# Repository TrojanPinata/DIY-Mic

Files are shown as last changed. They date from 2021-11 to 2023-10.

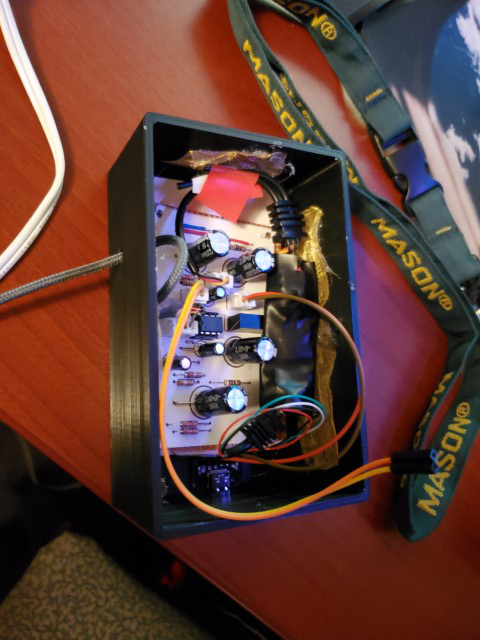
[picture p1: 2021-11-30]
pics/Assembled-Box (Small).jpg

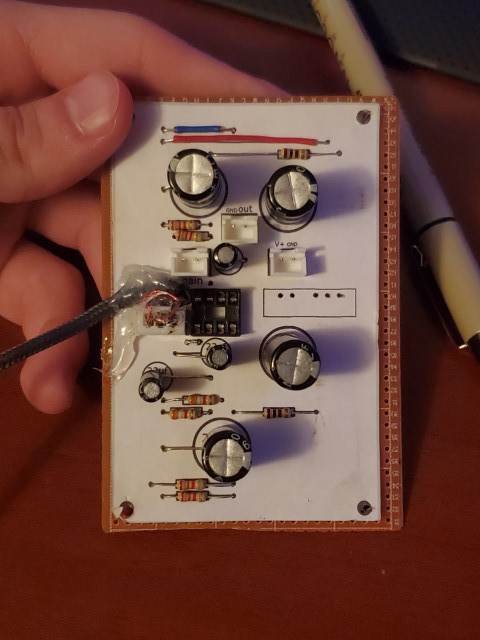
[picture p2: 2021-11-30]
pics/Partially-Assembled (Small).jpg

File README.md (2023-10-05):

# DIY-Mic
A DIY microphone built using the design of DIY Perks and modified by me. I wanted a decent mic and I didn’t want to spend the money on one, so when I saw this video it seemed like the perfect opportunity for me to both have fun with a electronics project and get a decent mic.

# Credit
This would not be possible without DIY Perks and the resources he provided. The stripboard and base wiring diagram are extremely helpful as well as his overall attention to detail. Video link here: https://www.youtube.com/watch?app=desktop&v=LoQu3XXIayc

# Acquiring Parts
For this build, there are a number of parts you will need. In the video he goes all out in brass, which for most of us at home, seems absurd because of how uncommon it is to have the exact diameter of brass tubing or brass mesh lying around. I ran into this problem early on, so I designed a box and lid for mine that should work in place of a ton of brass and wood and is easily 3d printable (STLs above). I know most people don't have 3d printers, but I feel like this is slightly more accessible for those without hordes of tools. I also used a mic arm I found in the trash to make the arm instead of building it. So, with the 'housing' out of the way, everything else can be found in this list (or at least what I used/needed):

https://docs.google.com/spreadsheets/d/1pQlkRerO5geoDNLEWXTUVbyJalM7nESn/edit#gid=497893649

As you can probably tell, the pricing is pretty high compared to the sticker price. That was the number I was able to get it down to after some alternatives (and using the wrong materials and finding out they don’t work. The electronics can either be found on alibaba or ebay, I chose ebay because that was the only way I could finish this in less then 2 months. With all of that, I nicked a old audio cable, a old rc car motor, and some resistors in order to start building.

# Actually Building the Thing
The first thing I did (and this pretty much goes with the order the parts arrived to me) was the preamp box. I put some brass mesh on the bottom and glued the template on some protoboard, soldered all of the parts on and drilled corner holes. In hindsight, the pegs I included were pretty useless (and off center) so they should probably just be removed. I layered some tape over the bottom mesh to prevent shorts and plopped the whole thin in. I then added the potentiometer to the lid. Note, I live in the US, so I was unable to get a THAT1512, and I had to go with an INA217. This isn't really a problem, just know that on my final build, I attached a 2.2kOhm resistor to the potentiometer because of how the gain settings work. I assume there may be some overall gain differences, but we'll get to that in the review section. I pretty much did that and threw in the ADC (Analog Digital Converter) with some tape covering it. I ordered a pretty cheap one, but it has a led and I kind of like that because of how much easier it made troubleshooting. All of these parts can be connected to the main board and the ADC can be connected to the USB-C breakout board. Power wires can be connected and that should be everything that is directly connected.

Partially Assembled:



Some notes real quick before putting anything on the board:



The two capacitors on the right need to be flipped 180 degrees so the polarities are swapped, and all of the rest are fine, with the white being positive and dark being negative. Other than that, you can build it however you want. I found that its better to use a little bit thicker audio cable, because the stuff that i used was really thin and I ended up having to solder it a bit to get the connectors to stay on.



And on that note lets talk about the cables. So yes, you can use solder removing copper strips like he did. But I had extremely bad luck with mine all just being flat to begin with, and thus not folding back into a tube. So as a result, I just ordered some proper sheathing. Honestly, worth it. I ended up threading the enameled wires through much easier than I thought it would be. So, with those two out of the way, IU soldered them together and used a heatshrink for the binding. Now, I just want to note that the way DIY Perks sands the enamel off of those thin wires is correct, however, be extremely careful because if you go too far, they are super easy to short (trust me I know from experience). So, with that, you can plug the cable into the preamp and work on the mic. 



The mic, from my experience, has the parts that take the longest to get here. First of all, if you can get a JLI mic module, be my guest, but they seem to be always out of stock. I ordered mine from another place for a significant markup and I'm not even mad. At least it’s here. The transistors took a hot minute to get here (they were the last thing I needed, and I actually moved on to another project I got so sick of waiting on them. Once they did arrive though, its pretty much exactly as he said. However, I should note my module housing is also 3d printed and the grills are shaped using 3d printed parts. Crushed the mesh in between the mold and formed the grills, soldered them with the transistor mic combo like a sandwich, and jammed it into the housing. I added all of those holes for maximum sound quality, and it seems to work. I will note that you should probably put something between the grill and transistor, as well as between the legs due to possible shorting, as that is what caused a lot of my early trouble. With that, that’s basically everything. I used some tape to secure the lid onto the box and hot glue to keep some loose things secured and it just kind of works. 



The rear of the module is really jank for me. Don't do this lol:



# Review
Overall its a good mic. I've been using it for the past few weeks and everyone who’s seen it really likes it. It's kind of scuffed but sounds fantastic (most of the time). I should note that I had a insane amount of gain until I added a resistor between the potentiometer. I still do, and I probably just need more shielding, but it sounds fine over discord and for personal use so I don't mind too much. I'll fix it when I need it. 

The big things about this project I would note for anyone looking to do this is that a.) it costs more then you expect, b.) it's not going to look anything like the video, and c.) there will be more noise then you think there will be. Other then that, happy building!

# Edit - 02/11/2022
Hello, I thought I was done with this project but let me tell you I've got a update that may interest you. Back when I was picking out the parts for this, I chose to use a INA217 because it was available and the only way for me to get a THAT1512 was a long 4 month wait from the UK. So, I bought the THAT1512 and the INA217 and hoped it would work out. I used the INA217 for the past few months and I can say its definitely good. Not great, not bad, just good. And I was happy with that. I had to use a higher resistance resistor in place of the potentiometer but overall, I didn't really mind it. There was a little bit of background noise at some frequencies, but I just thought that was my bad shielding.

I just got my THAT1512, slapped that bad boy in there and let me tell you, it's a whole world of difference. The two chips should be very electrically similar according to their data sheets, with only a little bit of gain differences, but the difference is insane. No more noise went back to the potentiometer, better volume (even at the same levels), and overall, a better time. Anyway, hope that interests you. They're kind of hard to find so if you can get one then do. Otherwise INA217 is still pretty good.

# Update - 10/05/2023
Hello! It has been a while. I never thought I'd update this repository again, but I just wanted to stop in after a while and clean up by bringing some modifications to the original project and overall design. I found the original mic design to be pretty cool, but horribly inconvenient to use. I ended up switching to another microphone for a while, but I thought I'd come back with some real quality of life changes to make this actually usable for me. The main things I changed were swapping the housing for a BM-800 microphone body (one of the worst sounding mics on the market - but cheap to fit with the theme) and designing a PCB which follows the original stripboard. My PCBs totaled a cool five dollars, and the quality of the entire thing is significantly higher. 

The end result was much better than the original, with significantly less noise and much more versatility. I added the KiCad files to the repo but don’t expect too much. I found the mic gets a bit hotter and has a much lower gain setting (100 ohms) due to the lower noise but is overall pretty good – especially when compared to the original. These upgrades make this 99% more usable for me and hopefully if you either still use this project or something similar this update is helpful.

mic exposed

mic together

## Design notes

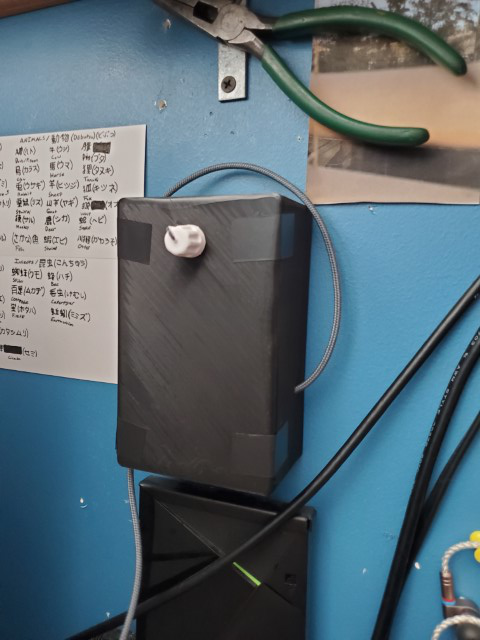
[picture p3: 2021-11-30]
pics/Magic-Box (Small).jpg

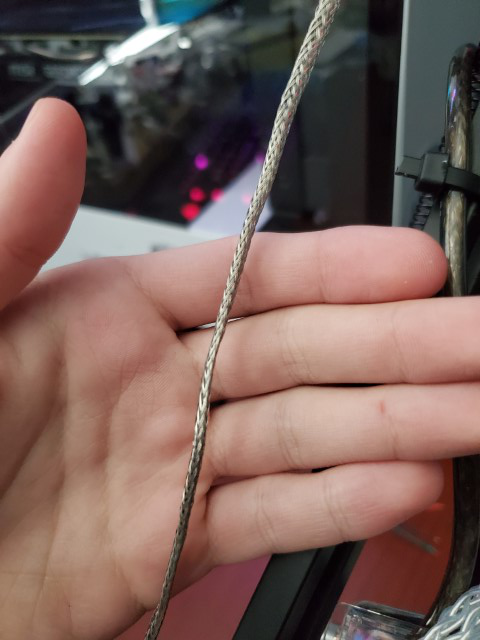
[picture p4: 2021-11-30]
pics/Cable (Small).jpg

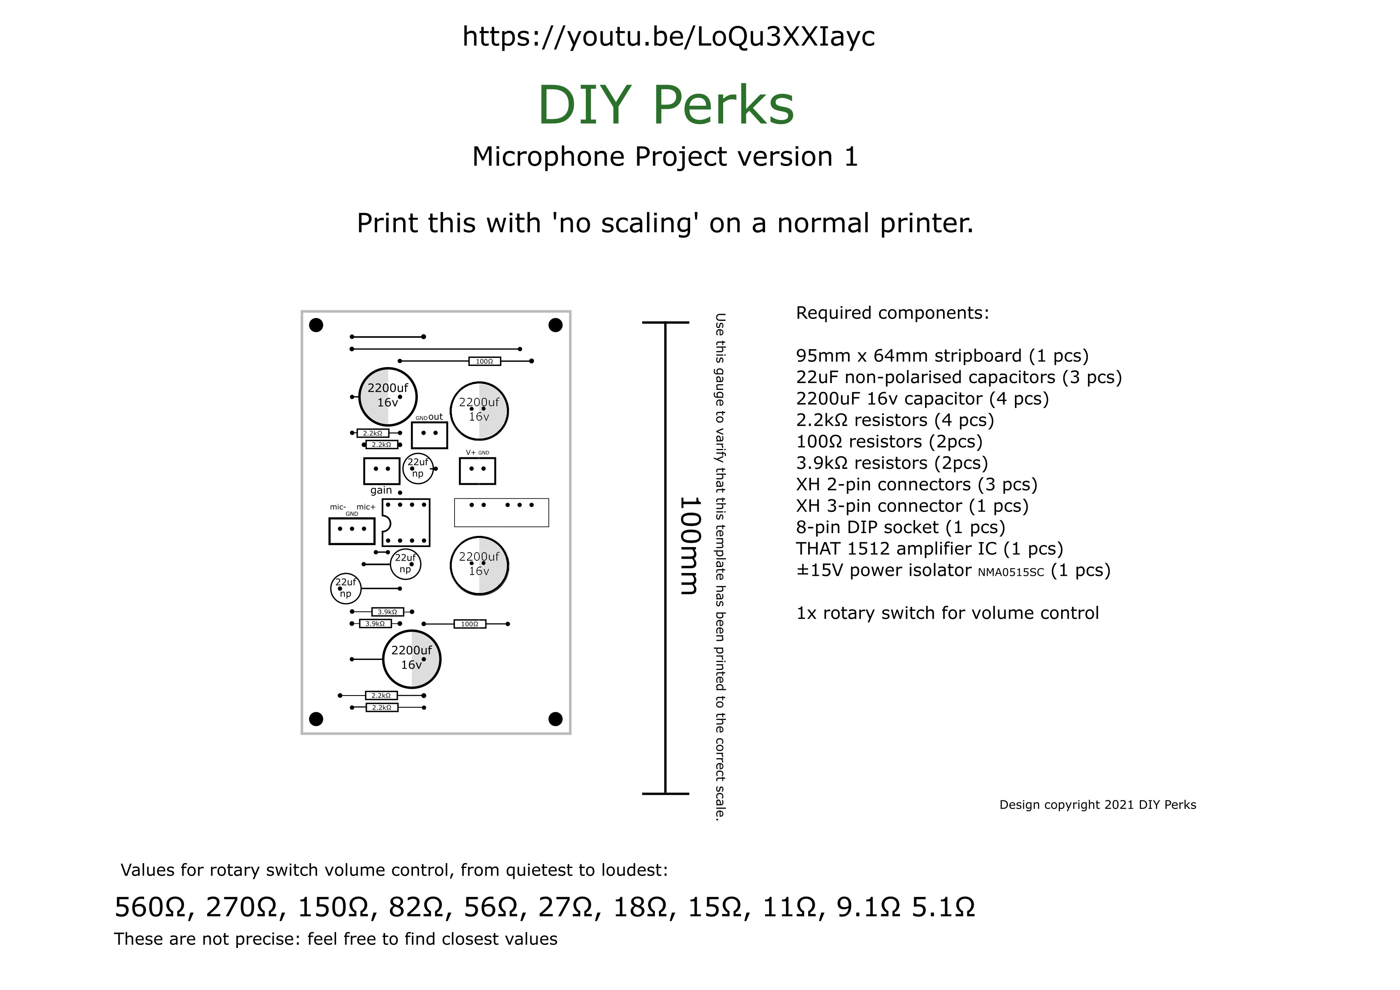
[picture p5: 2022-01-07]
new stripboard.png

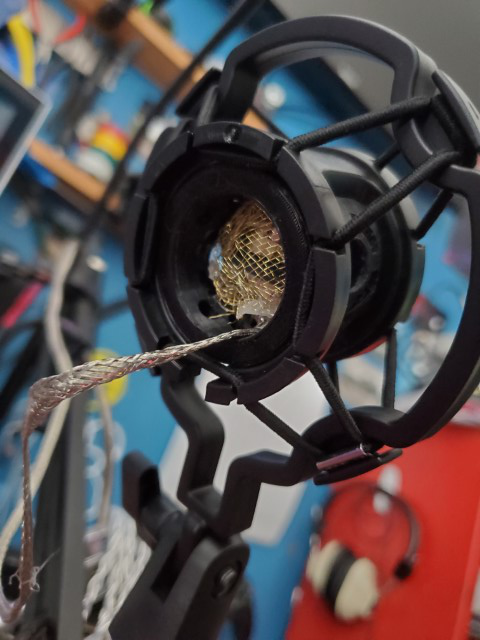
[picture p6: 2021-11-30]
pics/Rear (Small).jpg

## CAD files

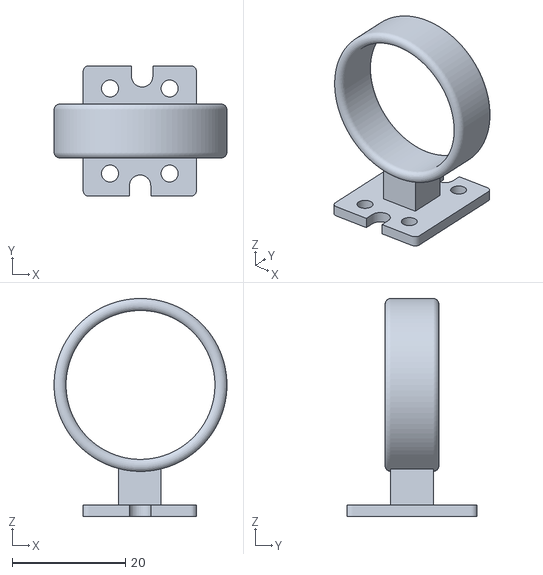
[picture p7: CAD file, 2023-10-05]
stls/micmoduleholder.stl
30.5 x 23.0 x 38.4

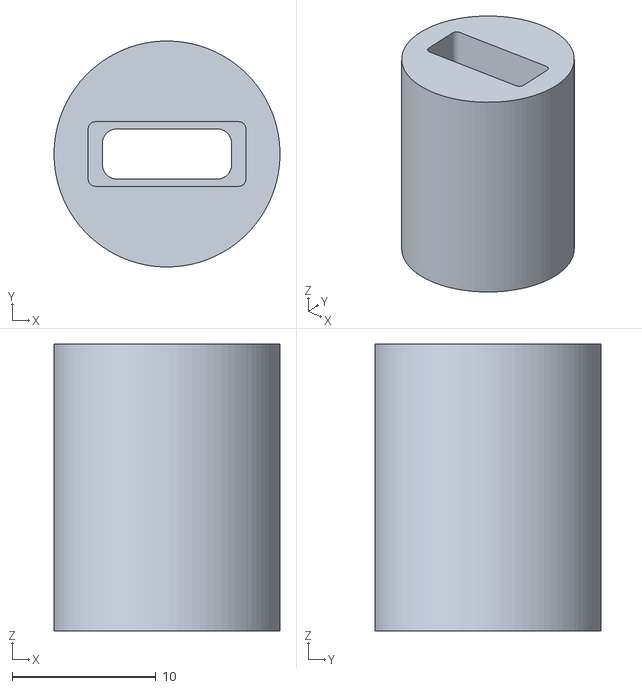
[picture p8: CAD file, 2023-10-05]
stls/xlr2usbc.stl
15.7 x 15.7 x 20.0

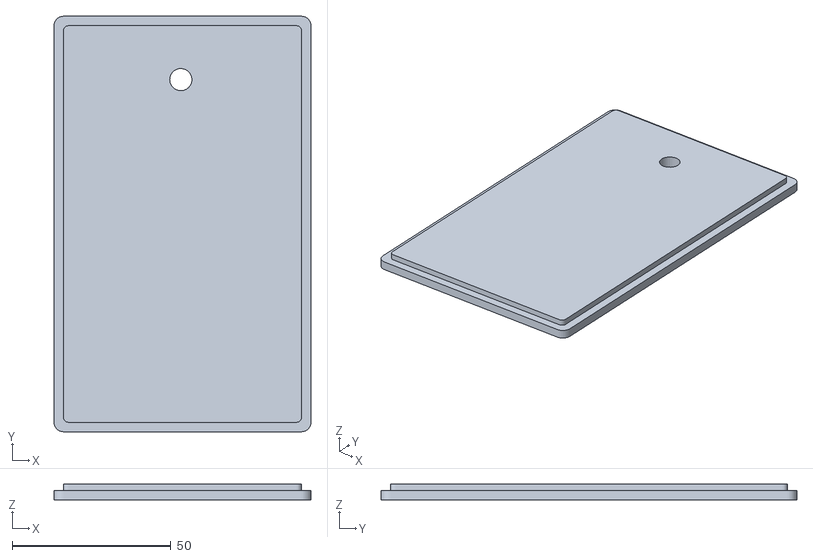
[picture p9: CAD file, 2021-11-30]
stls/top v3.stl
81.0 x 131.0 x 5.00

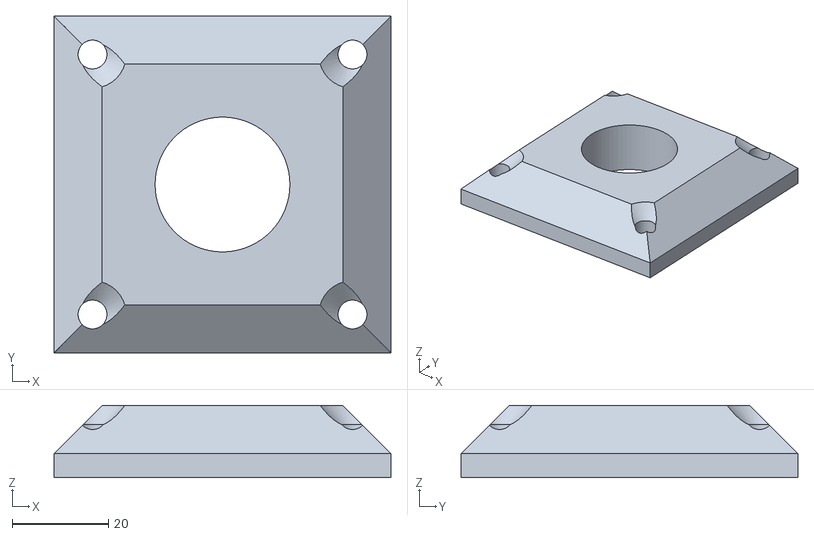
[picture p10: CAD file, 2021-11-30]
stls/press base v1.stl
70.0 x 70.0 x 15.0

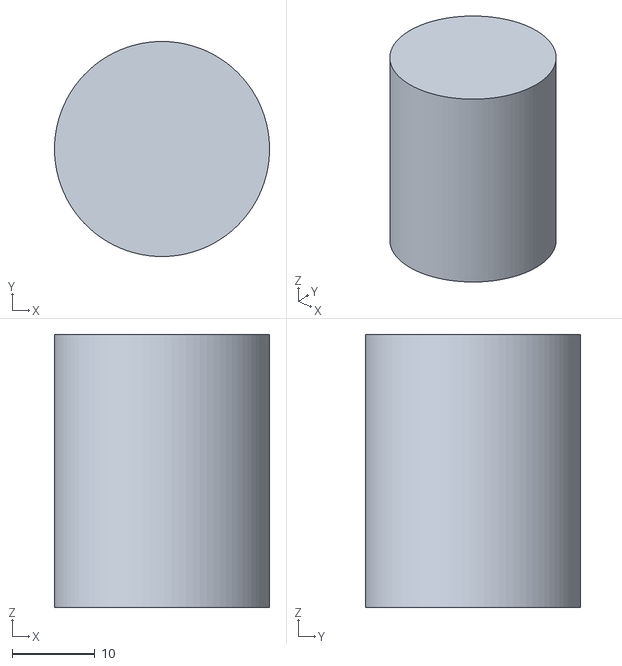
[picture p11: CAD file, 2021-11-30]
stls/press rod v2.stl
26.0 x 26.0 x 33.0

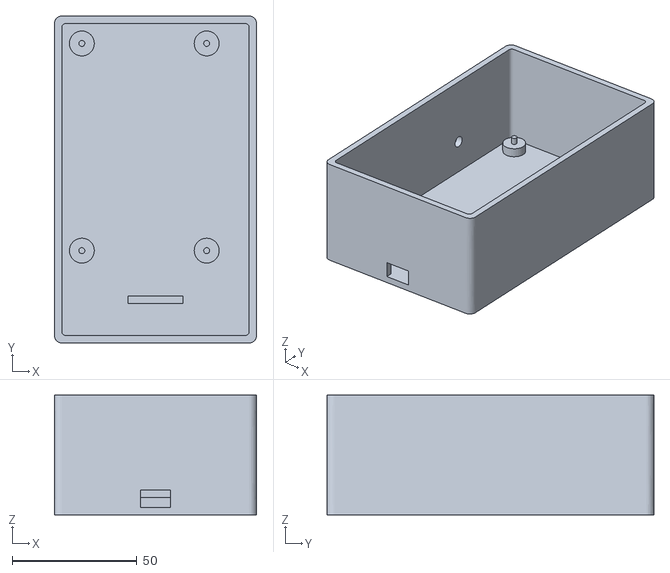
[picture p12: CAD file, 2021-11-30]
stls/base box v2.stl
81.0 x 131.0 x 48.0

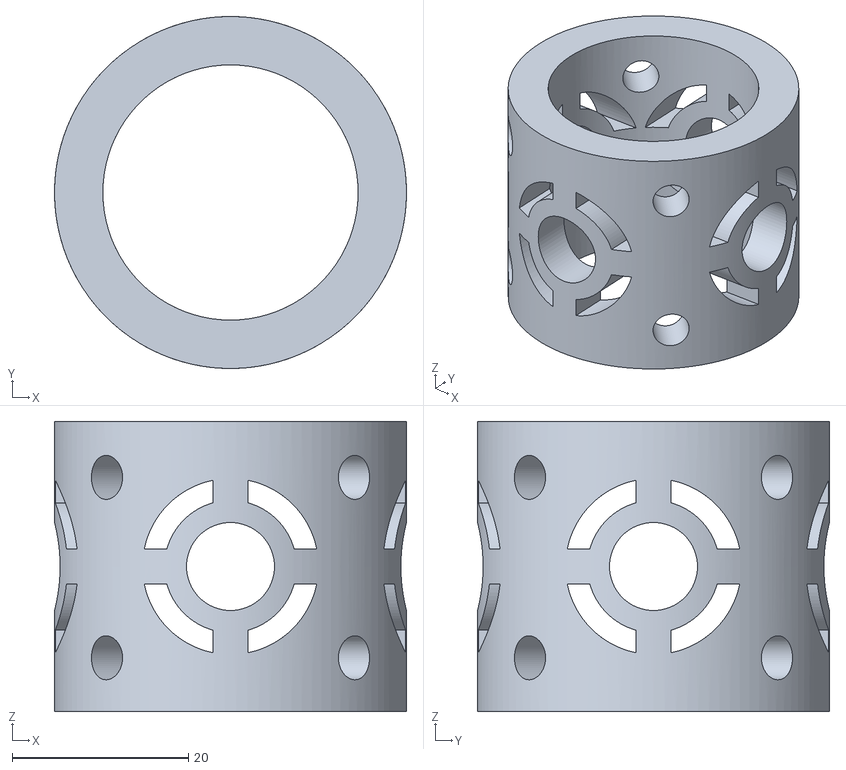
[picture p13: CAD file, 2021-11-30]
stls/module holder v2.5.stl
40.0 x 40.0 x 33.0

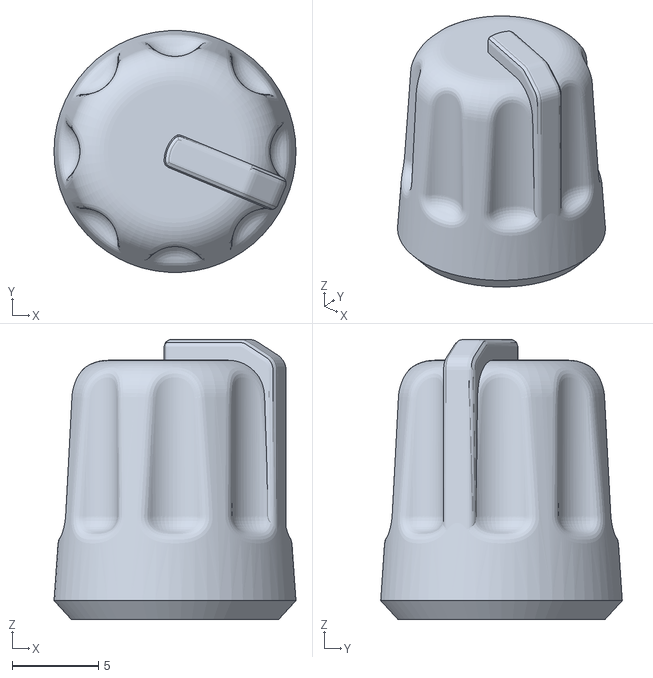
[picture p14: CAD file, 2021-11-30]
stls/knob_1_with_indicator.stl
14.0 x 14.0 x 16.2

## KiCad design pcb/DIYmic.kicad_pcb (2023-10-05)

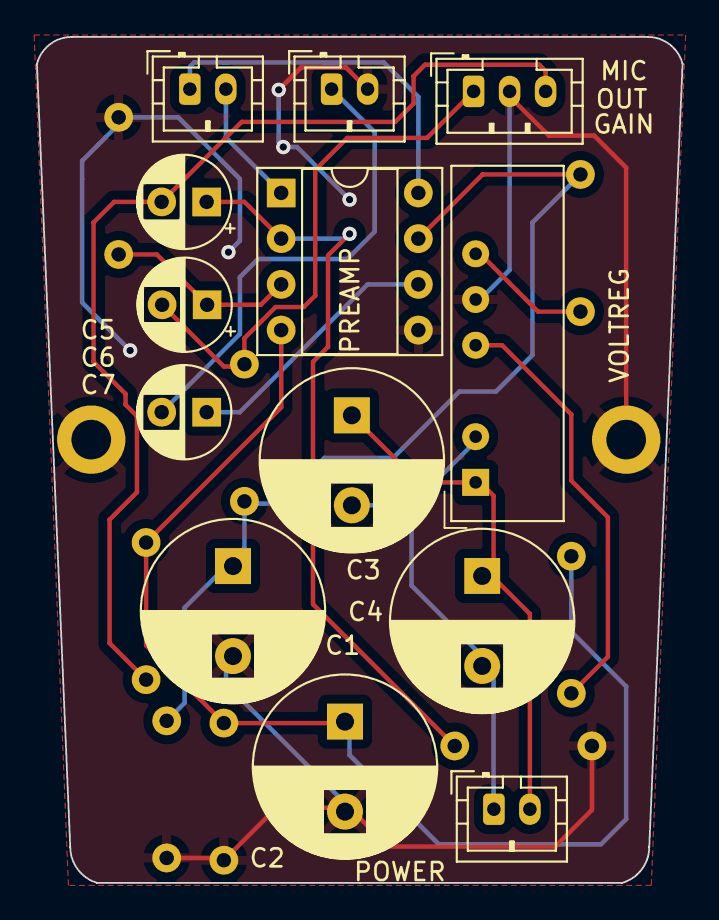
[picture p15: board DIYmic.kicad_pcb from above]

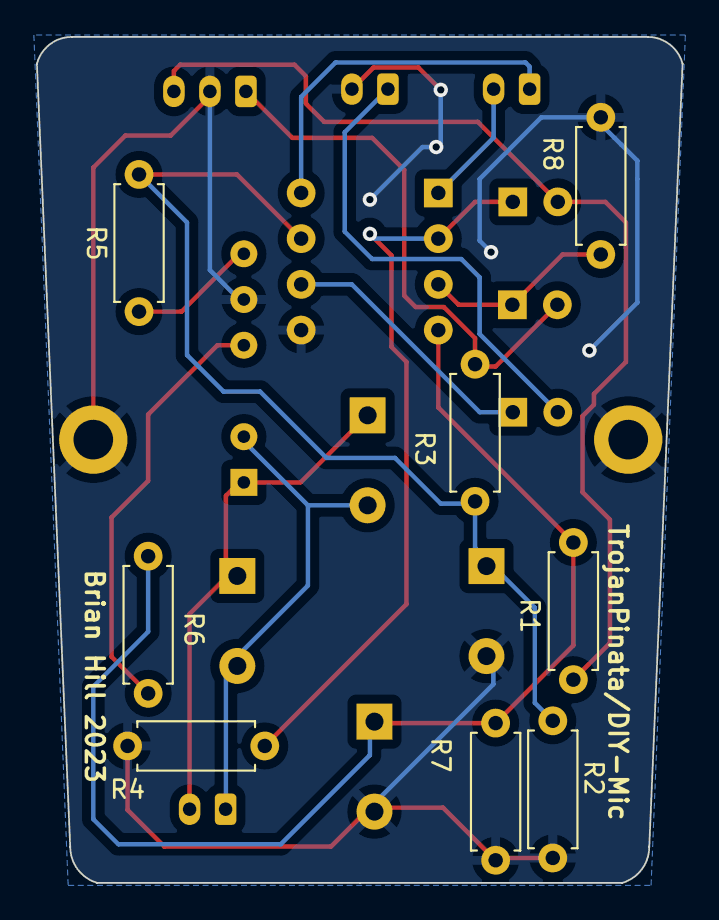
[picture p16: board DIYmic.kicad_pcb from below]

Board: 2 copper layers, 35.9 x 47.0 mm, 21 parts (8 on the bottom side), 15 nets.

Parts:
C1, C2, C3, C4: 2200uF; CP_Radial_D10.0mm_P5.00mm
C5, C6, C7: 22uF; CP_Radial_D5.0mm_P2.50mm
GAIN: Conn_01x02_Socket; JST_PH_B2B-PH-K_1x02_P2.00mm_Vertical
MIC: Conn_01x03_Socket; JST_PH_B3B-PH-K_1x03_P2.00mm_Vertical
OUT: Conn_01x02_Socket; JST_PH_B2B-PH-K_1x02_P2.00mm_Vertical
POWER: Conn_01x02_Socket; JST_PH_B2B-PH-K_1x02_P2.00mm_Vertical
PREAMP: THAT1512; DIP-8_W7.62mm_Socket
R1, R2, R3, R7: 2.2k; R_Axial_DIN0207_L6.3mm_D2.5mm_P7.62mm_Horizontal
R4, R8: 3.9k; R_Axial_DIN0207_L6.3mm_D2.5mm_P7.62mm_Horizontal
R5, R6: 100; R_Axial_DIN0207_L6.3mm_D2.5mm_P7.62mm_Horizontal
VOLTREG: NMA0515SC; Converter_DCDC_Murata_NMAxxxxSC_THT

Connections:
unnamed: GAIN.1, PREAMP.8
unnamed: GAIN.2, PREAMP.1
unnamed: C5.2, MIC.1, R3.2
unnamed: C1.2, C2.2, MIC.2, OUT.2, PREAMP.5, R2.2, R4.2, R7.2, R8.2, VOLTREG.5 (0V)
unnamed: C6.2, MIC.3, R1.2
unnamed: C7.2, OUT.1
unnamed: C3.2, C4.2, POWER.1, VOLTREG.2 (VIN-)
unnamed: C3.1, C4.1, POWER.2, VOLTREG.1 (VIN+)
unnamed: C6.1, PREAMP.2, R4.1
unnamed: C5.1, PREAMP.3, R8.1
unnamed: C2.1, PREAMP.4, R1.1, R6.2, R7.1
unnamed: C7.1, PREAMP.6
unnamed: C1.1, PREAMP.7, R2.1, R3.1, R5.2
unnamed: R5.1, VOLTREG.6 (VOUT+)
unnamed: R6.1, VOLTREG.4 (VOUT-)

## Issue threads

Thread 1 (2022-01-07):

Confusion: schematic and description don't match

JonnyPhenomenon, 2022-01-07:
in your description you said "The two capacitors on the right need to be filpped 180 degrees so the polarities are swapped" - but your schematic shows only one cap at the bottom with negative on the right, and the top three are negative on the left.

...I see in your picture of the completed board that you have installed the two caps on the right side with negative on the right...

Why did you have to make this change?  and could you update the diagram to reflect the change?

What does the back of this board look like?

TrojanPinata, 2022-01-30:
I saw this a couple of weeks ago and flipped the capacitors in the diagram. To clarify, all that means is that you take the two on the far right (one above and below the V+ and GND inputs) and swap which pin goes in which hole. The reason for this is due to polarity of capacitors and having them reversed would mean they never charge (you can read a more detailed explanation someone left on the stripboard image in the gdrive). I didn't really make that obvious in this write up so I apologize, I should have been more clear what I was referencing (and replying in a timely manner lol). As for the back of this board, it looks exactly the same, nothing different from the original. I actually didn't take any pictures of the back when I put it together or I would have posted them here, but it's glued in now and I'm afraid to disassemble it too much. If I do find something I'll update the readme to show a more detailed view from all angles.

Closed 2022-04-22.

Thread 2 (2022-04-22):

Audio grabber and potentiometer connection

janse96, 2022-04-22:
Hi! I'm happy that I came across your github and that you explained what has to be changed in the schematic, but I couldnt find any info about how to connect the amp to the grabber (the side with the 3 cables). I first used one of the cinch cables but while testing I noticed the only sound i get is when i touch the AUX connector so i changed the connection to that cable. I'm also unsure on how to connect the potentiometer correctly. I just used a 501 potentiometer instead of the rotary switch and I don't know if that's the problem or not, but a variable resistor should do the job just fine.

TrojanPinata, 2022-04-22:
I did the same thing you did with the potentiometer. I couldn’t find a rotary switch either and I ended up using a 1k potentiometer and it worked fine (granted you are using a THAT 1512 as the TI chips are screwy and have different gain thresholds, which you should then just use a 3k resistor or something). That alone shouldn’t cause a problem. Connecting should be as simple as using a Dupont connector on the potentiometer and a white JST connector for the board. If you’re really unsure you could just solder the positive to the right or left most pin and the other wire to the center pin (on the potentiometer that is).

As for the connections, I also found the JST connectors (the white connectors with the metal insert grabber things) to be kind of a pain. Tbh, I soldered them together by using a few tiny drips of solder on the cables to the metal grabbers and then forcing them in with tweezers. The whole thing is kind of scuffed (similar to splicing the hair thin mic wire with the standard size audio cable). I’m not exactly sure which connection you switched but it should be from the aux input to the mic, which is what it sounds like you did. Really the only thing I can advise is to check your connections and shielding. My shielding on the mic (the wire mesh) is really finicky and if it as so much as shakes it will press up against the transistor and cut audio. Stuff like that doesn’t sound too important but I thought it was being caused by something else for the longest time and resoldered so many connections.

This is kind of a mess and I'm making some assumptions, but I hope that helps!

janse96, 2022-04-23:
thanks for replying so fast! I already noticed some things that couldnt be right yesterday. For example the voltage was nowhere 15V and it all came back to the fact that i mistakenly soldered the GND connection from board to the free GND pin on the audio grabber PCB. I noticed the voltage there was just 0.3V but after resoldering it directly to the black  cable from the USB cable i got the right voltages and even sound! The only thing still bothering me is that a change from the potentiometer doesnt really affect the volume and the volume stays pretty low and to hear anything i have to raise my PC volume up quite a bit. Any idea of why that is? Also i get alot of noise when the capsule is not grounded to anything. No problem when i touch it or hold it but something isnt right.

TrojanPinata, 2022-04-23:
From my experience quiet audio is caused by the resistance in the potentiometer being too high for the gain pin on the chip. What the potentiometer controls is gain, and from what I can tell it's pretty sensitive. Make sure your potentiometer is linear (as opposed to logarithmic) and relatively low resistance, say around 1k. If after changing the potentiometer the volume is still really low, swap it for a low resistance resistor (like 100 - 500) and try that. If you're sound improves or is too loud you can tune appropriately from there and then if you determine the potentiometer is the problem, swap it out or insert a resistor at a comfortable volume. I've had cheap potentiometers burn out on me and they either become like shorted wires or broken circuits where no current passes through. If swapping it for lower and lower resistances doesn't change the situation and stright up bridging the connection doesn't improve it and you still have sound but its really quiet, then I think there is some other underlying problem that I'm not sure about.

Also, assuming you are on Windows, check your sound device settings and make sure volume is around 80/90 or whatever you are comfortable with. For some reason on first plug in mine was really low so double check that if you haven't already.

As for the capsule, yeah. That's really all. It's super noisy if it’s not perfectly balanced and I don't know a way to fix it. I spent a while trying to make a version two of just the capsule module, but I haven’t figured out a way to make it look good while maintaining the grounding and wire contacts. It's supposed to be connected to the ground wire of the mic but from my experience it almost never connects completely and makes a decent noise dampener. The best I could do was increasing the depth of the mesh to give it a ton of clearance and soldering everything together to make a perfect seal. I found that the THAT chip cleaned up a bit of the noise, but overall, it’s just annoying enough that I either hold the sheathed cable when doing super high quality recording or use a audio editor to clean it up in post (crisper or whatever in discord makes it unnoticeable). Realistically you could probably run another cable (one of the enameled thin ones) on the outside solely for the purpose of grounding (which I might actually do now that I think about it) but realistically there are a few ways to try and fix the noisiness of the capsule.

Sorry for the novel, hopes this sheads some light on getting those last few things fixed.

janse96, 2022-04-23:
I appreciate every detail! I will play around with the gain settings and see if anything changes… for the grounding of the capsule however I might just live with it if everything else works out ok. I used all parts exactly like the video proposes just without the swap to usb c, the potentiometer and the overall look/housing. I got some aluminum mesh and will use that for the capsule housing but I haven’t decided yet how the overall look of the mic should be. I’m thinking of buying a boom arm and using your housing for the capsule to insert it in the spider. I might still have some time to come up with something different but I’ll focus on the electronics first. It should work properly before it looks good :) thanks for the help!

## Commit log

2021-11-30 Added pics
    [base box v2.stl, knob_1_with_indicator.stl, module holder v2.5.stl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]
2023-10-05 feature update - quality of life and clean up
    [DIYmic-B_Cu.gbr, DIYmic-B_Mask.gbr, DIYmic-B_Paste.gbr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]
2026-03-31 Capacitor C2 Note
